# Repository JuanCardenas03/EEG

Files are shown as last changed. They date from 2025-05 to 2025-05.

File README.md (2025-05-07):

# 🧠⚡ EEG CEGS – Sistema de Captura y Procesamiento de Señales Cerebrales 🧠⚡

> Proyecto desarrollado por estudiantes de Ingeniería Electrónica - UCEVA  
> ¡Captura, procesa y analiza la actividad eléctrica del cerebro con ESP32-S3 y PCB personalizada!

---

## 📋 Descripción del Proyecto

Este proyecto tiene como objetivo el diseño e implementación de un sistema funcional de **electroencefalograma (EEG)**, capaz de capturar y procesar señales cerebrales en tiempo real.

Se ha diseñado una **máquina de estados finita (FSM) tipo Moore**, programada en la **ESP32-S3**, que controla las fases del sistema: desde la captura de señales hasta la presentación del resultado, usando indicadores visuales (LEDs) y entradas táctiles (`Touch 1` y `Touch 2`) para interactuar con el flujo.

---

## 🧩 Características principales

- ✅ Captura de señales EEG por medio de entrada analógica (ADC)
- ✅ Procesamiento interno de señales para detección de transiciones (alfa/beta)
- ✅ Máquina de estados con 4 fases: reposo, captura, procesamiento, resultado
- ✅ Control con sensores táctiles capacitivos (touch)
- ✅ Indicadores LED para mostrar estado del sistema en tiempo real
- ✅ FSM implementada en lenguaje C++ sobre el framework de Arduino
- ✅ PCB diseñada en **Autodesk EAGLE**, lista para fabricación 🛠️📦

---

## 🛠️ Tecnologías y herramientas usadas

- 🔹 ESP32-S3 (WiFi + Touch + ADC + potencia de procesamiento)
- 🔹 EAGLE para diseño de la PCB
- 🔹 Arduino Framework (ESP-IDF también compatible)
- 🔹 Procesamiento básico de señales EEG (FFT futura)
- 🔹 Pantalla OLED para retroalimentación visual
- 🔹 LEDs para retroalimentación visual

---

## 🚀 Estado del proyecto

> En desarrollo activo – se encuentra en fase de pruebas de la FSM y captura de señal.  
> Próximamente se integrará la lógica de procesamiento alfa/beta y se enviará la PCB a fabricación.

---

## 🤝 Aportaciones

¿Tienes experiencia en procesado de señales cerebrales, diseño de filtros, o análisis?  
¡Contribuye con este proyecto abierto! 😄

---

## 📜 Licencia

Este proyecto está bajo licencia **MIT**.  
Puedes usar, modificar y compartir el código libremente, siempre dando crédito a los autores.

---

**Proyecto académico desarrollado por estudiantes de Ingeniería Electrónica – UCEVA**

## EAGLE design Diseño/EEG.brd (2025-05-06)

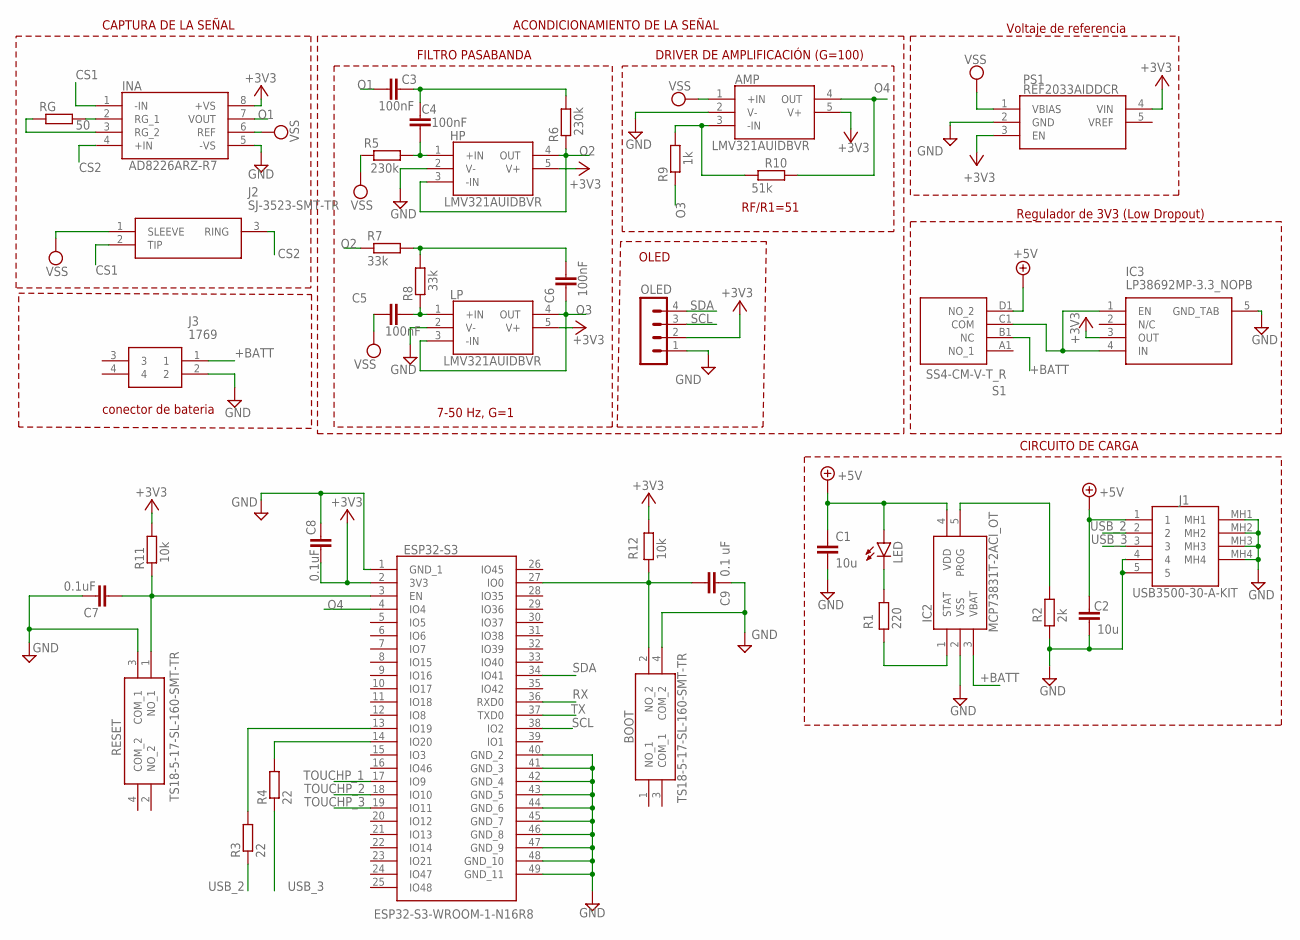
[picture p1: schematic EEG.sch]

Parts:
AMP: LMV321AUIDBVR; SOT95P280X145-5N
BOOT: TS18-5-17-SL-160-SMT-TR; TS18517SL160SMTTR
C1, C2: 10u; C0805K
C3, C4, C5, C6: 100nF; C0805
C7, C8: 0.1uF; C0805
C9: 0.1 uF; C0805
ESP32-S3: ESP32-S3-WROOM-1-N16R8; ESP32S3WROOM1N16R8
HP: LMV321AUIDBVR; SOT95P280X145-5N
IC2: MCP73831T-2ACI_OT; SOT95P270X145-5N
IC3: LP38692MP-3.3_NOPB; SOT150P700X180-5N
INA: AD8226ARZ-R7; SOIC127P600X175-8N
J1: USB3500-30-A-KIT; USB350030AKIT
J2: SJ-3523-SMT-TR; SJ3523SMTTR
J3: 1769
LED: LEDCHIPLED_0805; CHIPLED_0805
LP: LMV321AUIDBVR; SOT95P280X145-5N
OLED: MA04-1
PS1: REF2033AIDDCR; SOT95P280X110-5N
R1: 220; R0805
R2: 2k; R0805
R3, R4: 22; R0805
R5, R6: 230k; R0805
R7, R8: 33k; R0805
R9: 1k; R0805
R10: 51k; R0805
R11, R12: 10k; R0805
RESET: TS18-5-17-SL-160-SMT-TR; TS18517SL160SMTTR
RG: 50; M0805
S1: SS4-CM-V-T_R; SS4CMVTR

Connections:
+3V3: AMP.5 (V+), C8.1, ESP32-S3.2 (3V3), HP.5 (V+), IC3.3 (OUT), INA.8 (+VS), LP.5 (V+), OLED.2, PS1.3 (EN), PS1.4 (VIN), R11.2, R12.2
+5V: C1.1, C2.1, IC2.4 (VDD), J1.1, LED.A, S1.D1 (NO_2)
+BATT: IC2.3 (VBAT), J3.1, S1.B1 (NC)
CS1: INA.1 (-IN), J2.2 (TIP)
CS2: INA.4 (+IN), J2.3 (RING)
GND: AMP.2 (V-), BOOT.4 (COM_2), C1.2, C2.2, C7.1, C8.2, C9.1, ESP32-S3.1 (GND_1), ESP32-S3.40 (GND_2), ESP32-S3.41 (GND_3), ESP32-S3.42 (GND_4), ESP32-S3.43 (GND_5), ESP32-S3.44 (GND_6), ESP32-S3.45 (GND_7), ESP32-S3.46 (GND_8), ESP32-S3.47 (GND_9), ESP32-S3.48 (GND_10), ESP32-S3.49 (GND_11), HP.2 (V-), IC2.2 (VSS), IC3.5 (GND_TAB), INA.5 (-VS), J1.4, J1.5, J1.MH1, J1.MH2, J1.MH3, J1.MH4, J3.2, LP.2 (V-), OLED.1, PS1.2 (GND), R2.1, RESET.3 (COM_1)
unnamed: IC2.5 (PROG), R2.2
unnamed: LED.C, R1.2
unnamed: C6.1, R7.2, R8.1
unnamed: C4.2, HP.1 (+IN), R5.2
unnamed: C3.2, C4.1, R6.2
unnamed: C5.1, LP.1 (+IN), R8.2
unnamed: AMP.3 (-IN), R9.2, R10.1
unnamed: INA.2 (RG_1), RG.2
unnamed: IC2.1 (STAT), R1.1
unnamed: IC3.1 (EN), IC3.4 (IN), S1.C1 (COM)
unnamed: INA.3 (RG_2), RG.1
unnamed: BOOT.2 (NO_2), C9.2, ESP32-S3.27 (IO0), R12.1
unnamed: ESP32-S3.14 (IO20), R4.2
unnamed: ESP32-S3.13 (IO19), R3.2
unnamed: C7.2, ESP32-S3.3 (EN), R11.1, RESET.1 (NO_1)
O1: C3.1, INA.7 (VOUT)
O2: HP.3 (-IN), HP.4 (OUT), R6.1, R7.1
O3: C6.2, LP.3 (-IN), LP.4 (OUT), R9.1
O4: AMP.4 (OUT), ESP32-S3.4 (IO4), R10.2
RX: ESP32-S3.36 (RXD0)
SCL: ESP32-S3.38 (IO2), OLED.3
SDA: ESP32-S3.34 (IO41), OLED.4
TOUCHP_1: ESP32-S3.17 (IO9)
TOUCHP_2: ESP32-S3.18 (IO10)
TOUCHP_3: ESP32-S3.19 (IO11)
TX: ESP32-S3.37 (TXD0)
USB_2: J1.2, R3.1
USB_3: J1.3, R4.1
VSS: AMP.1 (+IN), C5.2, INA.6 (REF), J2.1 (SLEEVE), PS1.1 (VBIAS), R5.1

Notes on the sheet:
CAPTURA DE LA SEÑAL
ACONDICIONAMIENTO DE LA SEÑAL
FILTRO PASABANDA
DRIVER DE AMPLIFICACIÓN (G=100)
7-50 Hz, G=1
RF/R1=51
Voltaje de referencia
CIRCUITO DE CARGA
Regulador de 3V3 (Low Dropout)
conector de bateria
OLED

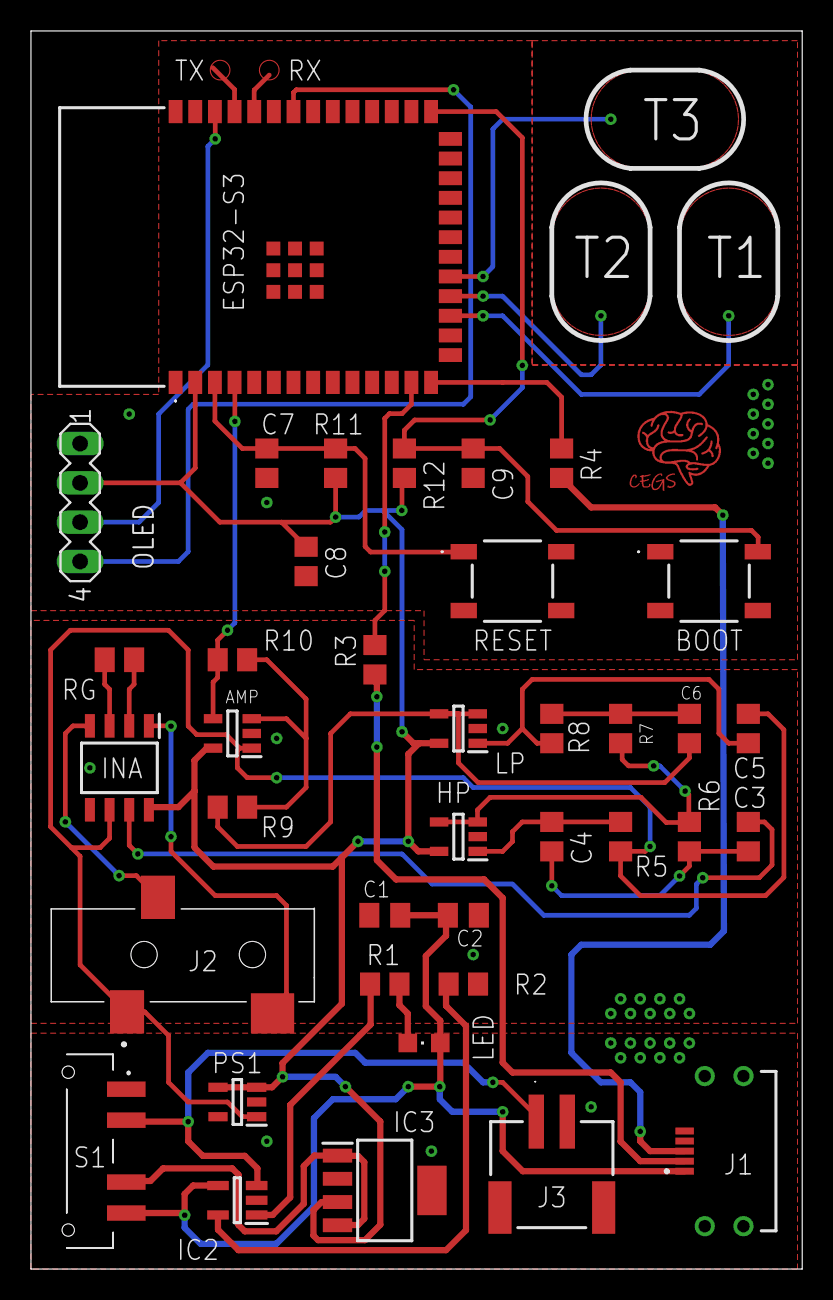
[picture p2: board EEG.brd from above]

Board: 2 copper layers, 49.8 x 80.0 mm, 38 parts (0 on the bottom side), 30 nets.

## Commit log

2025-03-22 Solo creé el archivo del esquema
    [EEG.sch]
2025-03-23 INA medio agregado
    [EEG.sch]
2025-03-23 Se agregó la forma del filtro pasa banda
    [EEG.sch]
2025-03-25 Se añadió la forma del driver amplificador
    [EEG.sch]
2025-03-25 Reestructurando el proyecto
    [EEG.sch]
2025-03-25 Carpeta del diseño
    [EEG.sch]
2025-03-25 Librerías de los componentes
2025-03-25 Se agregó el filtro Notch
2025-03-29 Se reemplazó el INA y se agregó la ESP32 (faltan por configurar)
    [EEG.sch]
2025-03-31 se quita el filtro Notch ; a la espera de corregir valores de salidas
2025-03-31 se quita el filtro Notch ; a la espera de corregir valores de salidas v2
    [EEG.sch]
2025-03-31 Agregue el voltaje de referecia y conexiones de los amplificadores
    [EEG.sch]
2025-03-31 correccion de tierras y entradas 3v3 añadidas (cositas varias)
2025-03-31 correccion de tierras y entradas 3v3 añadidas (cositas varias) v2
    [EEG.sch]
2025-04-01 añadido lib de circuito de carga
2025-04-03 Añadido circuito de carga
2025-04-03 Añadido circuito de carga v3
    [EEG.sch]
2025-04-03 Añadí el regulador de 3V3 (Low Dropout)
    [EEG.sch]
2025-04-03 Se estableció valores de resistores y capacitores para los filtros y amplificadores
    [EEG.sch]
2025-04-04 Se subió circuito de la esp32 s3
    [EEG.sch]
2025-04-04 Se reorganizó un poco el esquema, se corrigieron algunos errores y se generó el archivo brd
    [EEG.brd, EEG.sch]
2025-04-04 arreglo de conexiones
    [EEG.sch]
2025-04-13 añadido libs para jack y usb, jack añadido falta conexion usb
2025-04-14 Se actualizo el diagrama de la ESP 32-S3
    [EEG.brd, EEG.sch]
2025-04-14 mod circuito de carga, amplificadores y filtros
    [EEG.brd, EEG.sch]
2025-04-16 Se actualizó la esp32-s3
    [EEG.brd, EEG.sch]
2025-04-16 Correcion de conexiones, añadido leds indicadores de estados FSM
    [EEG.brd, EEG.sch]
2025-04-23 Se cambiaron alguno nombres para evitar confusiones
    [EEG.brd, EEG.sch]
2025-04-24 Se adelantó la PCB separando los componentes por secciones de potencia, analógica y digital
    [EEG.brd, EEG.sch]
2025-04-24 añadí el conector de la bateria
    [EEG.brd, EEG.sch]
2025-04-25 enrutamiento y cambios en la conexion de bateria, Falta GND
    [EEG.brd, EEG.sch]
2025-04-25 Corrección Esp-32
    [EEG.brd, EEG.sch]
2025-04-25 añadido paths de resistencias de programación
    [EEG.brd]
2025-04-25 correciones de conexion
    [EEG.brd]
2025-04-26 arreglé todas las vias de la PCB
    [EEG.brd]
2025-04-26 Se agregaron los planos de tierra y se corregieron algunas pistas
    [EEG.brd]
2025-04-27 Se agregaron los touchpads
    [EEG.brd]
2025-04-29 Se corrigió un par de errores y añadió el logo
    [EEG.brd]
2025-05-02 añadido valores cap de carga
    [EEG.brd, EEG.sch]
2025-05-03 Correcciones del profesor
    [EEG.brd, EEG.sch]
2025-05-03 añadido oled, componentes nuevos, restio de leds y correcion de pistas
    [EEG.brd, EEG.sch]
2025-05-03 añadí las rutas del nuevo componente
    [EEG.brd]
2025-05-06 por fin acabamos esto
    [EEG.brd, EEG.sch]
